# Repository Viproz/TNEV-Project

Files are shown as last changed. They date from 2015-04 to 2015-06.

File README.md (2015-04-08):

# TNEV-Project

Pour installer l'ide : http://download.netbeans.org/netbeans/8.0.2/final/bundles/netbeans-8.0.2-cpp-windows.exe

L'installer puis installer le plugin Arduino : http://plugins.netbeans.org/plugin/46054/arduino (http://plugins.netbeans.org/download/plugin/2774)

Suivre le tuto ici : http://arduino-netbeans.googlecode.com/files/Install.pdf

Et voilà !

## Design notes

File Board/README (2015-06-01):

The file tnev.cam contains all the params needed to generate the file for the printer

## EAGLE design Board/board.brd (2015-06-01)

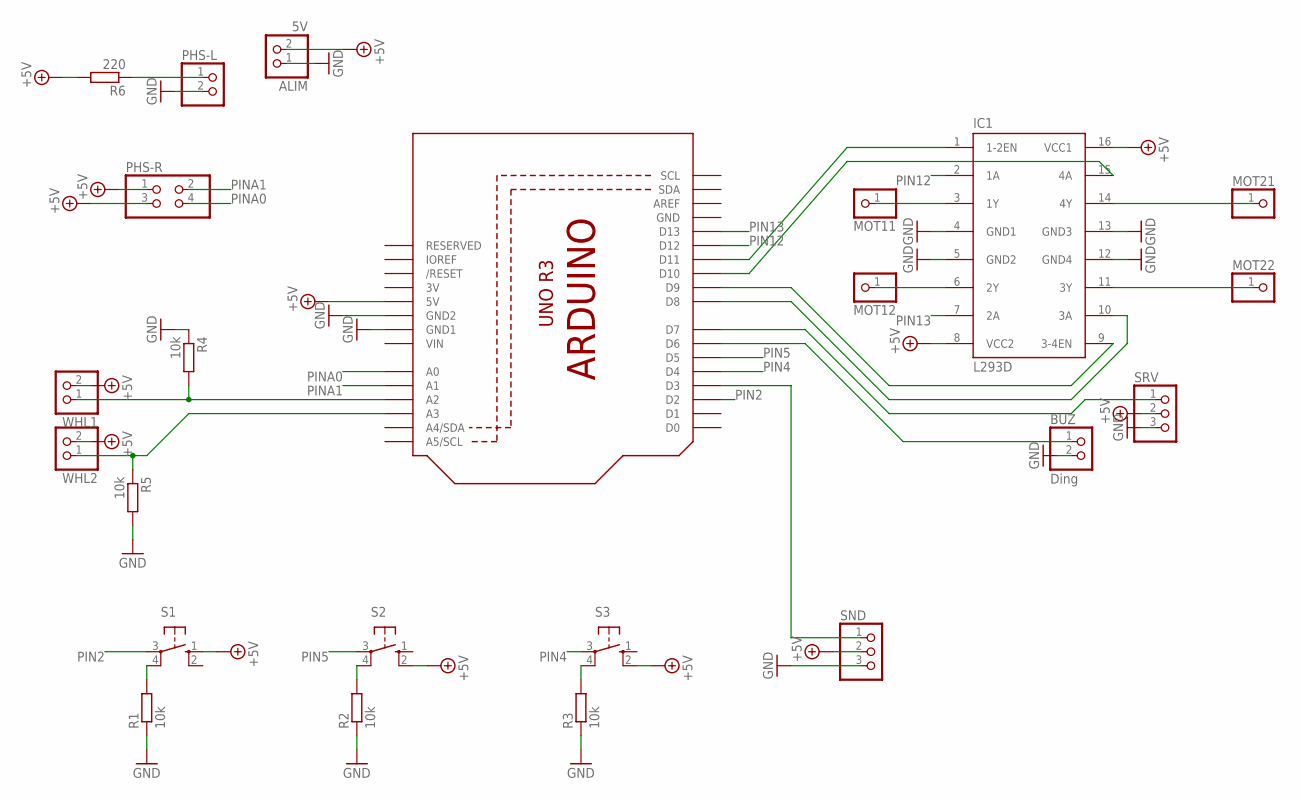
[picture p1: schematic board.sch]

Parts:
ALIM: 5V; 1X02
BUZ: Ding; 1X02
IC1: L293D; DIL16
MOT11, MOT12, MOT21, MOT22: PINHD-1X1; 1X01
PHS-L: PINHD-1X2; 1X02
PHS-R: PINHD-2X2; 2X02
R1, R2, R3, R4, R5: 10k; R1206
R6: 220; R1206
S1, S2, S3: 10-XX; B3F-10XX
SND: PINHD-1X3; 1X03
SRV: PINHD-1X3/90; 1X03/90
U1: ARDUINOR3-BPLACE
WHL1, WHL2: PINHD-1X2; 1X02

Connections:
3V: U1.3V
+5V: ALIM.2, IC1.8 (VCC2), IC1.16 (VCC1), PHS-R.1, PHS-R.3, R6.2, S1.1 (S), S2.2 (S1), S3.2 (S1), SND.2, SRV.2, U1.5V, WHL1.2, WHL2.2
GND: ALIM.1, BUZ.2, IC1.4 (GND1), IC1.5 (GND2), IC1.12 (GND4), IC1.13 (GND3), PHS-L.2, R1.1, R2.1, R3.1, R4.1, R5.2, SND.3, SRV.3, U1.GND, U1.GND1, U1.GND2
unnamed: IC1.3 (1Y), MOT11.1
unnamed: IC1.6 (2Y), MOT12.1
unnamed: IC1.14 (4Y), MOT21.1
unnamed: IC1.11 (3Y), MOT22.1
unnamed: IC1.15 (4A), U1.D10
unnamed: IC1.9 (3-4EN), U1.D9
unnamed: IC1.10 (3A), U1.D8
unnamed: IC1.1 (1-2EN), U1.D11
unnamed: R4.2, U1.A2, WHL1.1
unnamed: PHS-L.1, R6.1
unnamed: R5.1, U1.A3, WHL2.1
unnamed: SRV.1, U1.D7
unnamed: BUZ.1, U1.D6
unnamed: R2.2, S2.4 (P1)
unnamed: R3.2, S3.4 (P1)
unnamed: R1.2, S1.4 (P1)
unnamed: SND.1, U1.D3
PIN2: S1.3, U1.D2
PIN4: S3.3, U1.D4
PIN5: S2.3, U1.D5
PIN12: IC1.2 (1A), U1.D12
PIN13: IC1.7 (2A), U1.D13
PINA0: PHS-R.4, U1.A0
PINA1: PHS-R.2, U1.A1
VIN: U1.VIN

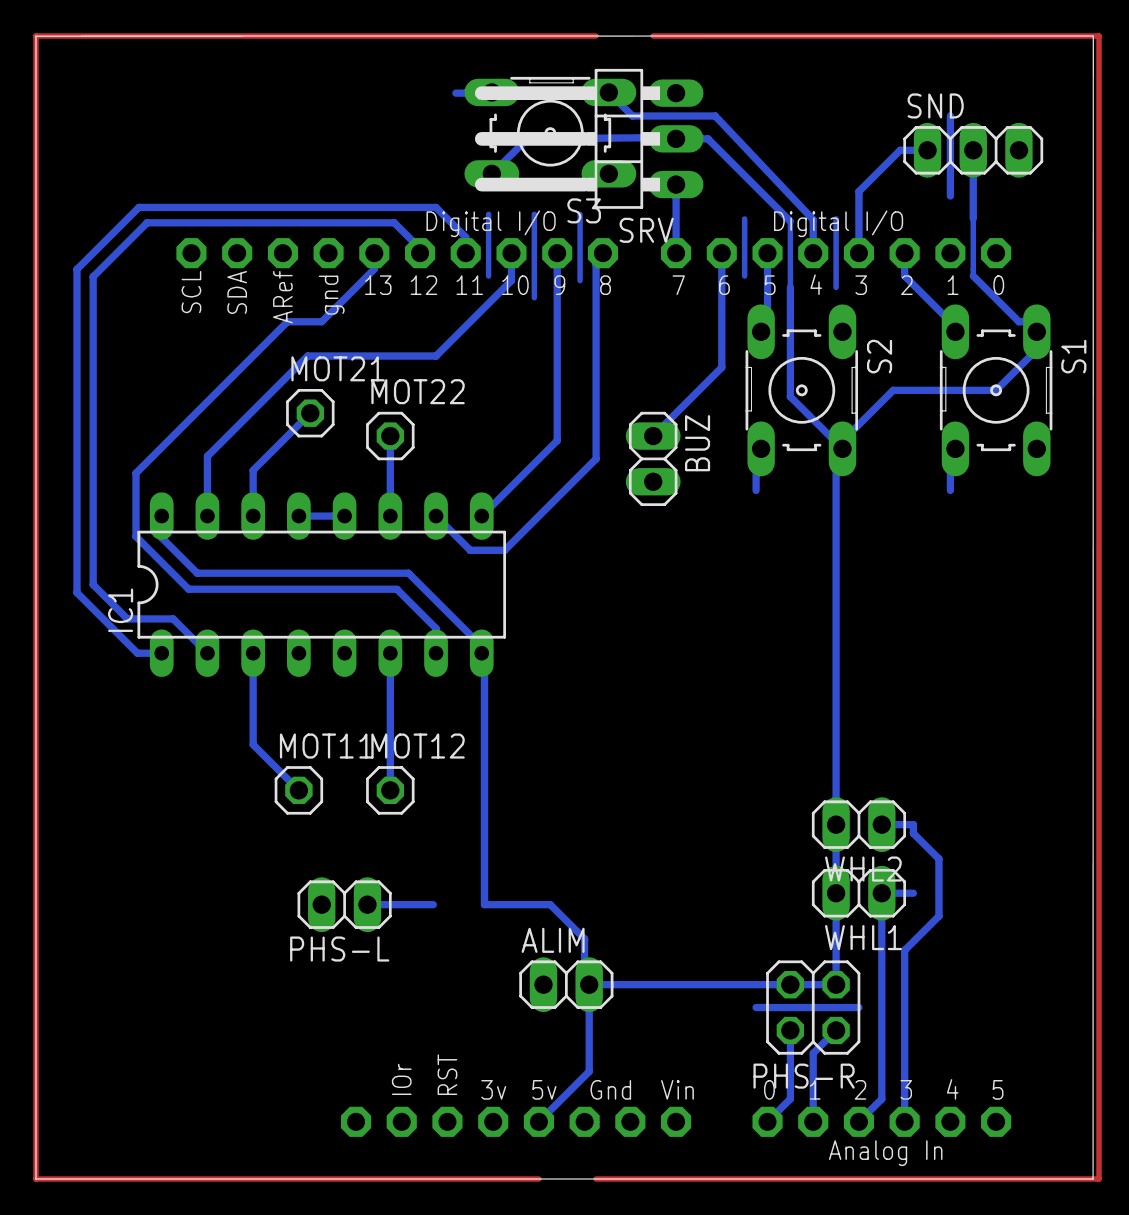
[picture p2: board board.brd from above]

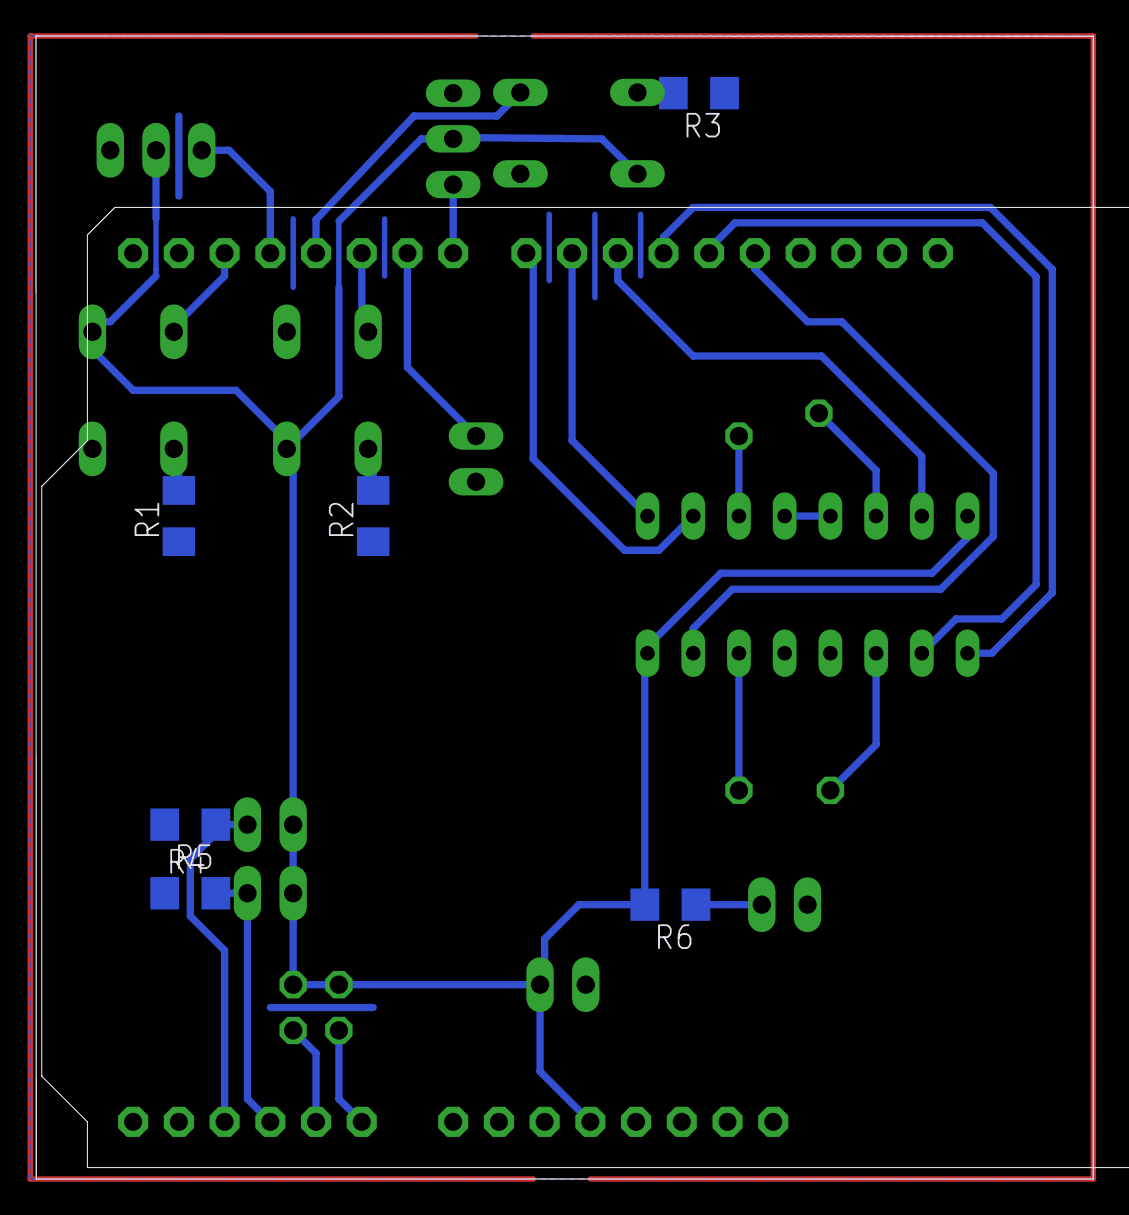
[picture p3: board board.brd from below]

Board: 2 copper layers, 58.7 x 63.5 mm, 23 parts (6 on the bottom side), 26 nets.

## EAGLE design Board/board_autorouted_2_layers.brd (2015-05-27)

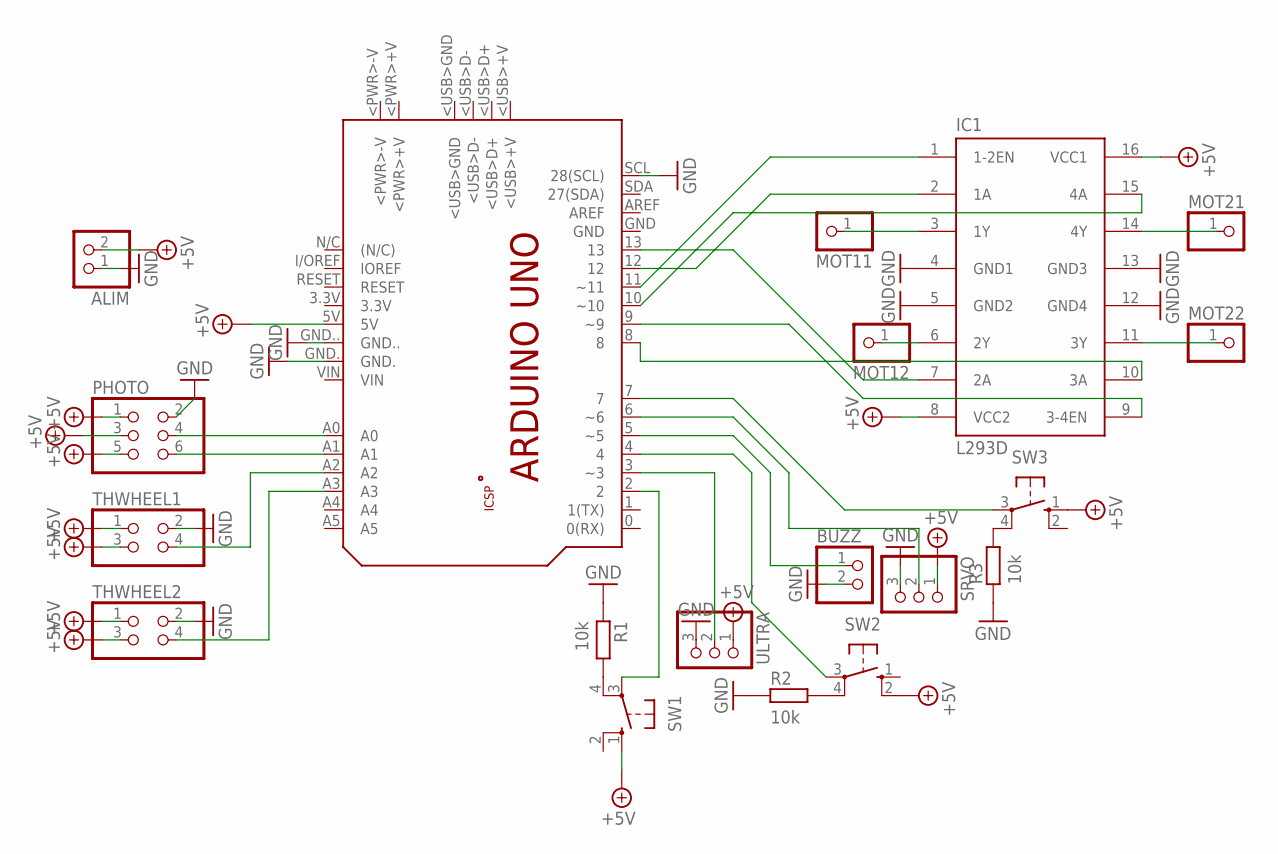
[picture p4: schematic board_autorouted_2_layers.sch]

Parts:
ALIM: PINHD-1X2; 1X02
BUZZ: PINHD-1X2; 1X02
IC1: L293D; DIL16
MOT11, MOT12, MOT21, MOT22: PINHD-1X1; 1X01
PCB1: ARDUINO_UNO
PHOTO: PINHD-2X3; 2X03
R1, R2, R3: 10k; R0603
SRVO: PINHD-1X3; 1X03
SW1, SW2, SW3: 40-XX; B3F-40XX
THWHEEL1, THWHEEL2: PINHD-2X2; 2X02
ULTRA: PINHD-1X3; 1X03

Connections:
+5V: ALIM.2, IC1.8 (VCC2), IC1.16 (VCC1), PCB1.5V, PHOTO.1, PHOTO.3, PHOTO.5, SRVO.1, SW1.1 (S), SW2.2 (S1), SW3.1 (S), THWHEEL1.1, THWHEEL1.3, THWHEEL2.1, THWHEEL2.3, ULTRA.1
GND: ALIM.1, BUZZ.2, IC1.4 (GND1), IC1.5 (GND2), IC1.12 (GND4), IC1.13 (GND3), PCB1.GND., PCB1.GND.., PCB1.SCL (28(SCL)), R1.1, R2.1, R3.1, SRVO.3, THWHEEL1.2, THWHEEL2.2, ULTRA.3
unnamed: IC1.3 (1Y), MOT11.1
unnamed: IC1.6 (2Y), MOT12.1
unnamed: IC1.14 (4Y), MOT21.1
unnamed: IC1.11 (3Y), MOT22.1
unnamed: IC1.2 (1A), PCB1.12
unnamed: IC1.7 (2A), PCB1.13
unnamed: IC1.15 (4A), PCB1.10 (~10)
unnamed: IC1.9 (3-4EN), PCB1.9 (~9)
unnamed: IC1.10 (3A), PCB1.8
unnamed: IC1.1 (1-2EN), PCB1.11 (~11)
unnamed: PCB1.A1, PHOTO.6
unnamed: PCB1.A0, PHOTO.4
unnamed: PCB1.6 (~6), SRVO.2
unnamed: PCB1.3 (~3), ULTRA.2
unnamed: BUZZ.1, PCB1.5 (~5)
unnamed: PCB1.7, SW3.3
unnamed: R3.2, SW3.4 (P1)
unnamed: PCB1.4, SW2.3
unnamed: R2.2, SW2.4 (P1)
unnamed: R1.2, SW1.4 (P1)
unnamed: PCB1.A2, THWHEEL1.4
unnamed: PCB1.A3, THWHEEL2.4
unnamed: PCB1.2, SW1.3

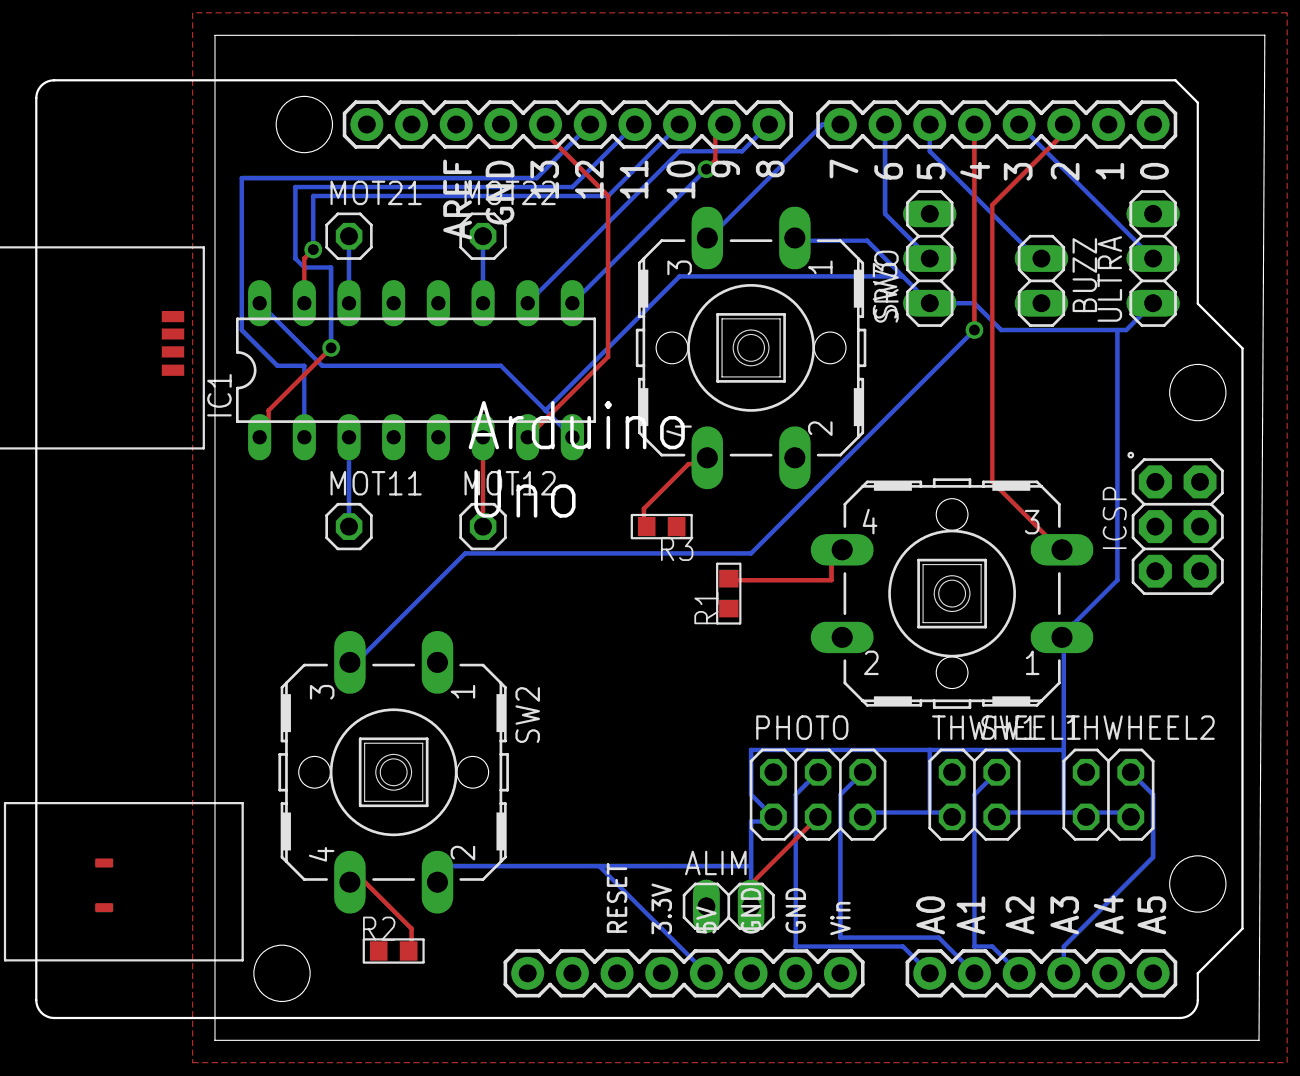
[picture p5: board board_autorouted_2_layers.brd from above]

Board: 2 copper layers, 69.8 x 57.1 mm, 19 parts (0 on the bottom side), 25 nets.

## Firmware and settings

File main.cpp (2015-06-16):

#include <Arduino.h>
//#include "src/Motor.h"
//#include "src/MotorCarriage.h"
#include "src/MotorSensor.h"
#include <HardwareSerial.h>
#include "src/Button.h"
#include "src/MotorCarriage.h"
#include "src/UltrasonicSensorCarriage.h"

//PINs Some pins are in MotorCarriage
#define PIN_START 2
#define PIN_STOP 5
#define PIN_CALIBRATE 4

Button *buttonStart;
Button *buttonStop;
Button *buttonCalibrate;

MotorCarriage motors;

MotorSensor* sensor;
UltrasonicSensorCarriage* sound;

void setup() {
    //Initialize variables and classes
    Logger::init();
    sensor = new MotorSensor(A0);
    buttonCalibrate = new Button(PIN_CALIBRATE);
    buttonStart = new Button(PIN_START);
    buttonStop = new Button(PIN_STOP);
     sound = new UltrasonicSensorCarriage();
}

void loop() {
    //Buttons
    if(buttonStop->pushed()) {
        Logger::log("pres.3se2d");
        int angle, dist = 1;
        sound->findNearest(angle, dist);
        Logger::log("Result : Angle & dist");
        Logger::log(angle);
        Logger::log(dist);
        sound->write(angle);
    }
    if(buttonStart->pushed()) {
        Logger::log("pressed");
        sound->reset();
        
        int angle, dist = 0;
        
        //Do the slalom
        sound->findNearest(angle, dist);
        motors.turn(90 - angle);
        sound->reset();
        dist = sound->getDistance();
        motors.goDistance(dist - 35);
        motors.turn(-90);
        motors.goDistance(35);
        motors.turn(90);
        motors.goDistance(70);
        sound->findNearest(angle, dist);
        //fix f
        motors.turn(90 - (angle - 45));
        motors.goDistance(70);
        
        
        
    }
    if(buttonCalibrate->pushed()) {
        motors.goDistance(20);
        //motors.calibrate();
        Logger::log("presse2d");
    }
}

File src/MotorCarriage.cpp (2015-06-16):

#include "MotorCarriage.h"

#define MOTOR1_CONTROL_PIN_1 13
#define MOTOR1_CONTROL_PIN_2 12
#define MOTOR1_ENABLE_PIN 11

#define MOTOR2_CONTROL_PIN_1 10
#define MOTOR2_CONTROL_PIN_2 8
#define MOTOR2_ENABLE_PIN 9

#define MOTOR1_SENSOR_PIN A5
#define MOTOR2_SENSOR_PIN A4

MotorCarriage::MotorCarriage() {
    rightSensor = new MotorSensor(MOTOR1_SENSOR_PIN);
    leftSensor = new MotorSensor(MOTOR2_SENSOR_PIN);
    
    rightMotor = new Motor(MOTOR1_CONTROL_PIN_1, MOTOR1_CONTROL_PIN_2, MOTOR1_ENABLE_PIN, rightSensor);
    leftMotor = new Motor(MOTOR2_CONTROL_PIN_1, MOTOR2_CONTROL_PIN_2, MOTOR2_ENABLE_PIN, leftSensor);
    
    
    maxSpeed = 28;
    
    setSpeed(0);
}

MotorCarriage::~MotorCarriage() {
    delete rightMotor;
    delete leftMotor;
    
    delete rightSensor;
    delete leftSensor;
}

/**
 * This will be used to calibrate the motors
 */
void MotorCarriage::calibrate() {
    //First step : Go forward
    leftMotor->setMaxVoltage(255);
    rightMotor->setMaxVoltage(255);
    rightSensor->reset();
    leftSensor->reset();
    setSpeed(100);
    unsigned long time = millis();
    Logger::log("there");
    while(true) {
        //With a timout of 10 sec
        if(millis() - time > 15000) {
            Logger::log("Calibration timeout");
            Logger::error();
            break;
        }
        if((rightSensor->tick() >= 20) & (leftSensor->tick() >= 20)) {
            break;
        }
    }
    setSpeed(0);
    //Get the minimal number of ticks
    int minIntersections = 0;
    
    //Check to see if one turned more then the other
    if(rightSensor->getIntersections() > leftSensor->getIntersections()) {
        minIntersections = leftSensor->getIntersections();
        rightMotor->setMaxVoltage(255.0 * ((float)leftSensor->getIntersections() / (float)rightSensor->getIntersections()));
        Logger::log(255.0 * ((float)leftSensor->getIntersections() / (float)rightSensor->getIntersections()));
    } else {
        minIntersections = rightSensor->getIntersections();
        leftMotor->setMaxVoltage(255.0 * ((float)rightSensor->getIntersections() / (float)leftSensor->getIntersections()));
        Logger::log(255.0 * ((float)rightSensor->getIntersections() / (float)leftSensor->getIntersections()));
    }
    
    //Get the speed in cm/s of the robot d = intersections * (2pi / number of intersections of the wheel) * radius of the wheel
    maxSpeed = (float)minIntersections * 19.415 / ((float)(millis() - time) / 1000.0);
}

/**
 * Change the speed of the carriage
 * 
 * @param percent Speed in percent
 */
void MotorCarriage::setSpeed(int percent) {
    leftMotor->setSpeed(percent);
    rightMotor->setSpeed(percent);
}

/**
 * Make the carriage turn
 * 
 * Be carefull this function is blocking
 * 
 * @param degree Angle in degree to turn, in trigonometric direction
 * @param speedPercent
 */
void MotorCarriage::turn(int degree, int speedPercent) {
    //Both wheels will move
    //d = angle / 2 * pi * (dist between the two wheels) / 180
    
    float sign = 1;
    
    //Reverse the sign to move in the othrt direction
    if(degree < 0)
        sign = -1;
    
    int d = (float)degree * 1.23;
    
    rightMotor->goDistance(d * sign);
    leftMotor->goDistance(-1 * d * sign);
    
    while(rightMotor->tick() | leftMotor->tick()) {
        //do nothing right now
    }
}

/**
 * Moves the carriage to some distance
 * 
 * Be carefull this function is blocking
 * 
 * @param centimeters Distance to move
 * @param speedPercent Speed in percent
 */
void MotorCarriage::goDistance(int centimeters, int speedPercent) {
    
    rightMotor->goDistance(centimeters, speedPercent);
    leftMotor->goDistance(centimeters, speedPercent);
    while(rightMotor->tick() | leftMotor->tick()) {
        //do nothing right now
    }
    
    
    /*//t = d / v
    float timeToMove = abs(centimeters) / maxSpeed / ((float)speedPercent / 100.0);
    
    int sign = 1;
    if(centimeters < 0)
        sign = -1;
    
    setSpeed(speedPercent * sign);
    delay(timeToMove * 1000.0);
    setSpeed(0);*/
}

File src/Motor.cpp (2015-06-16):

#include "Motor.h"
#include "Logger.h"
#include "MotorSensor.h"

Motor::Motor(uint8_t pinControl1, uint8_t pinControl2, uint8_t pinEnable, MotorSensor* sensor) :
pinControl1(pinControl1), pinControl2(pinControl2), pinEnable(pinEnable) , sensor(sensor)
{
    //Inititialize pins
    pinMode(pinControl1, OUTPUT);
    pinMode(pinControl2, OUTPUT);
    pinMode(pinEnable, OUTPUT);
    
    //Make sure the motor is stopped
    digitalWrite(pinEnable, LOW);
    
    //Before calibration maxVoltage is 255
    maxVoltage = 255;
}

/**
 * Changes the speed of the motor
 * 
 * @param percent Speed in percentage
 */
void Motor::setSpeed(int percent) {
    Logger::log("max thingy");
    Logger::log(maxVoltage);
    //For now simple conversion to 0 -> 255 later we may add calibration
    int motorSpeed = (float)percent / 100.0 * (float)maxVoltage;
    Logger::log(motorSpeed);
    
    if(motorSpeed < 0) {
        digitalWrite(pinControl1, LOW);
        digitalWrite(pinControl2, HIGH);
    } else {
        digitalWrite(pinControl1, HIGH);
        digitalWrite(pinControl2, LOW);
    }
    
    analogWrite(pinEnable, abs(motorSpeed));
}

void Motor::goDistance(int centimeters, int speedPercent) {
    
    //ta da dam
    centimeters *= 2;
    
    //We'll use the sensor to mesure
    previousAngle = sensor->getAngle();
    
    forward = centimeters >= 0;
    distToGo = abs(centimeters);
    setSpeed(speedPercent * (forward ? 1 : -1));
}

bool Motor::tick() {
    if(distToGo > 0) {
        int newAngle = sensor->getAngle();
        distToGo -= getArc(previousAngle, newAngle, forward);
        Logger::log(distToGo);
    }
    if(distToGo < 0) {
        analogWrite(pinEnable, 0);
        return false;
    }
    return true;
}

float Motor::getArc(int prevAngle, int newAngle, bool direction) {
    //direction == true means trigonometric rotation
    int angle = 0;
    
    
    if(abs(prevAngle - newAngle) < 5)
        return 0;
    
    if(!direction) {
        if(prevAngle > newAngle)
            angle = newAngle - prevAngle + 360;
        else
            angle = newAngle - prevAngle;
    }
    
    if(direction) {
        if(prevAngle < newAngle)
            angle = prevAngle - newAngle + 360;
        else
            angle = prevAngle - newAngle;
    }
    
    //Caluculate the arc length
    //d = PI*degree/180*r
    //diameter = 62cm
    Logger::log((float)angle * 0.0541);
    return (float)angle * 0.0541;
}

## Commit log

2015-04-22 Added Motor object
2015-04-22 Added MotorCarriage Object
2015-05-17 Added MotorSensor and calibration
2015-05-17 Added speed calibration, turn implementation and goDistance Added structure for Ultrasonic sensor
2015-05-21 added board stuff
    [board.brd, board.sch]
2015-05-27 various stuff and board
    [board.brd, board.sch]
2015-05-27 Eagle : Switches connected, useless backups deleted
    - Connected the switches left unconnected last time
    - Optimized the schematics
    - Removed the now useless backups & libraries - only kept the 3 most
    recent versions.
    [board.brd, board.sch]
2015-05-27 Eagle : Added thumbwheels
    [board.brd, board.sch]
2015-05-27 Finished, and autorouted everything on 2 layers.
    [board.brd, board_autorouted_2_layers.brd, board_autorouted_2_layers.sch]
2015-05-27 Optimization & 1-layer version
    - Made the schematics easier to read
    - Replaced blocks with individual pins - easier to know what is what
    once finished
    - Optimized for a single layer (90.7% success)
    - Some other minor things I forgot.
    [board_autorouted_1_layer.brd, board_autorouted_1_layer.sch, board_autorouted_2_layers-v2.brd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]
2015-05-31 Updated boad
    [board.brd, board.sch, board_autorouted_1_layer.brd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]
2015-05-31 Board cleanup
    [board.brd, board.sch]
2015-05-31 Added Button class Updated MotorSensor for the new system.
2015-05-31 Fixed Servo Various corrections main.cpp cleanup
    [MotorCarriage.cpp, MotorSensor.cpp, UltrasonicSensorCarriage.cpp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]
2015-06-01 Board preparation
    [board.brd]
2015-06-01 Board README
2015-06-01 Small changes
    [board.brd]
2015-06-03 Added UltrasonicSensor func Fixed and tweaked vales for calibration
    [MotorCarriage.cpp, MotorSensor.cpp, UltrasonicSensor.cpp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]
